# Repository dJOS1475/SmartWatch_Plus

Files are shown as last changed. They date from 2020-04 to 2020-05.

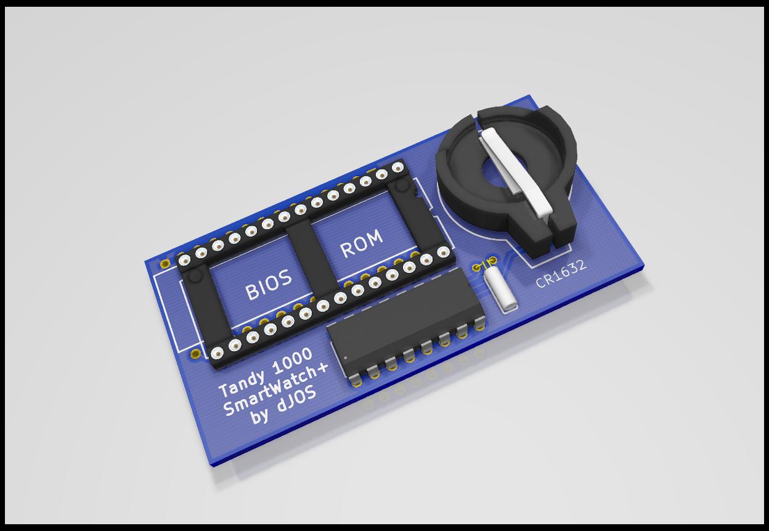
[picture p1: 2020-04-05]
Renders/SmartWatch+.jpg

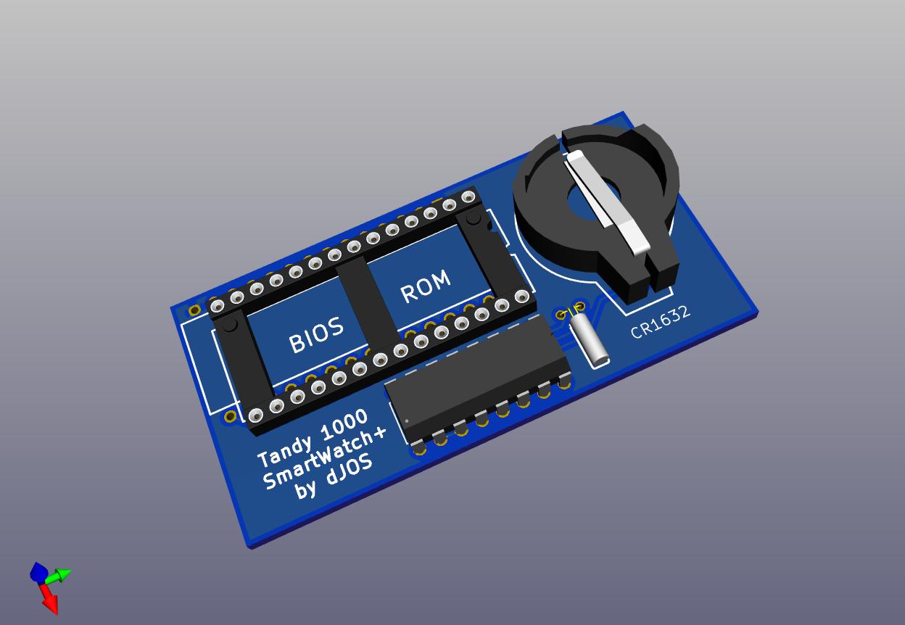
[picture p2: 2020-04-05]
Renders/SmartWatch+_Basic.jpg

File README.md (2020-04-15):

# SmartWatch_Plus
SmartWatch+ Tandy 1000 HX, SX etc Edition

The Tandy 1000 SmartWatch+ module adds a Clock & Calendar to your 1000. All you need to do is install it under the BIOS ROM and then use the Y2K Patched SMWCLOCK.COM utility to set the time automatically via your Autoexec.bat file.

I made this design because the original SmartWatch batteries are now mostly dead and can't be replaced. The 1000 SmartWatch+ uses a standard CR1632 Lithium coin cell for long life and easy replacement.

This HX/SX version should fit most Tandy 1000 machines (except the 1000 EX) but was designed for the HX and SX machines. If it physically fits in your 1000, it will work. it should also work in other PC Clones with a 28 Pin Bios ROM chip.

Y2K SmartWatch Software is here: https://www.dropbox.com/s/kctqpwzjxgymfz9/smwy2k.zip?dl=0

My Store can be found here: https://www.tindie.com/stores/CyberneticSys/

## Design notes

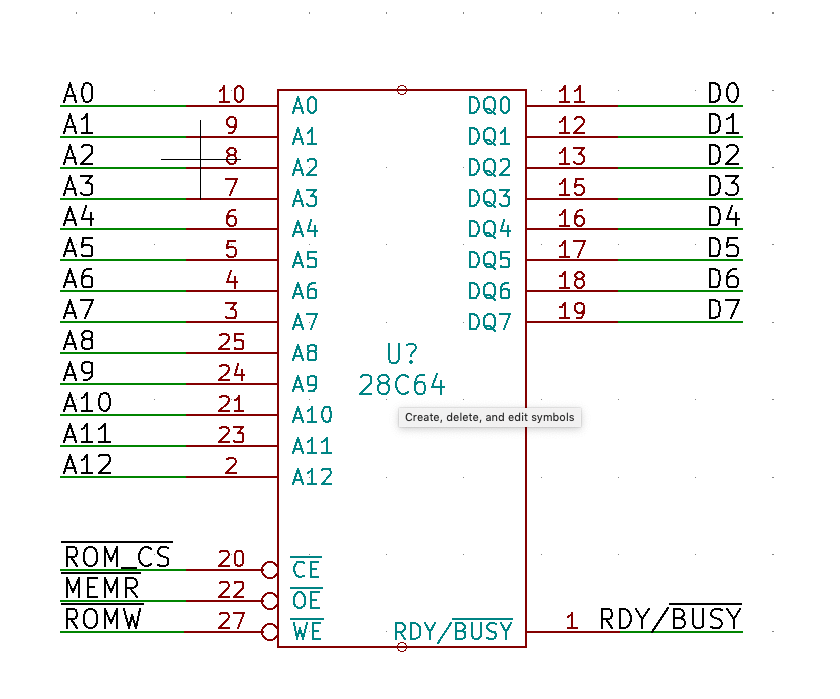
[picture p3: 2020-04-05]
Info/Screenshot 2019-10-07 15.42.38.png

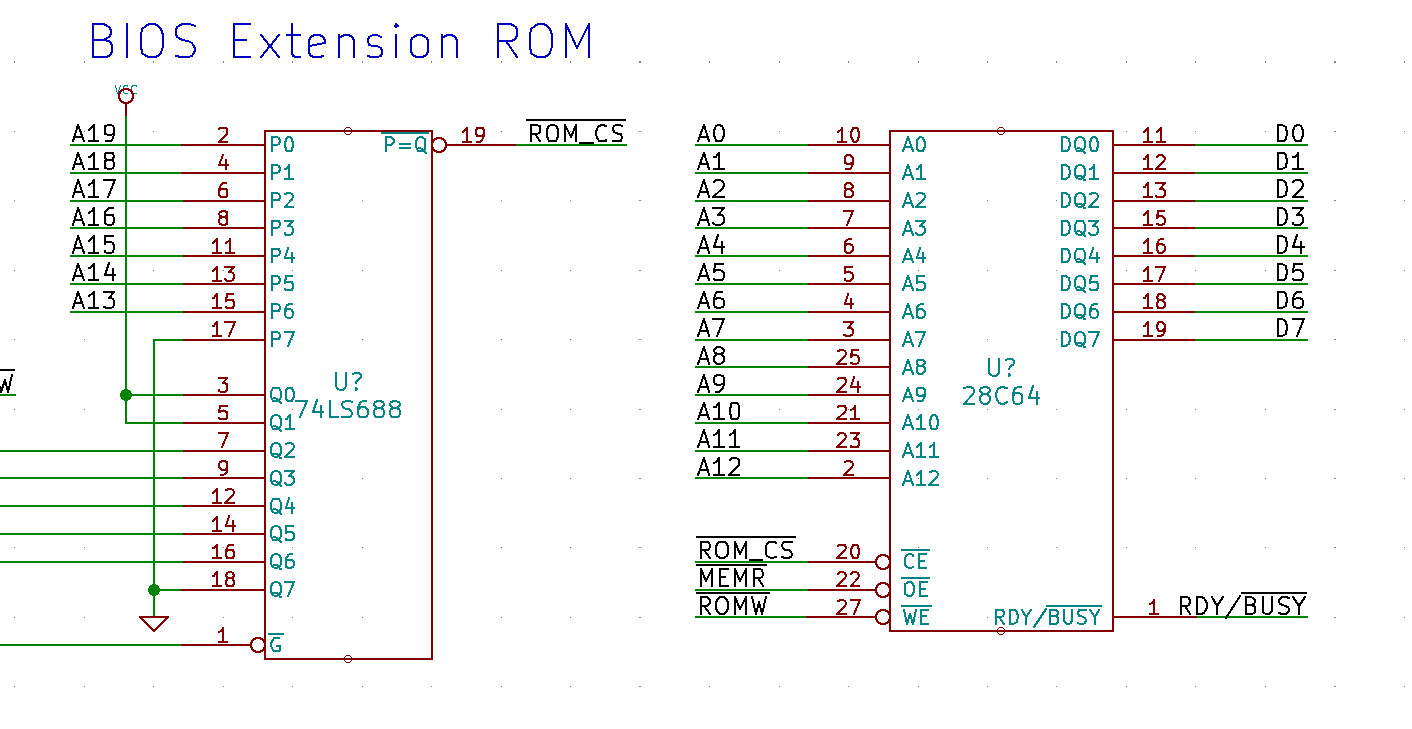
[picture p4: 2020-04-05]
Info/Screenshot 2019-10-07 15.09.33.png

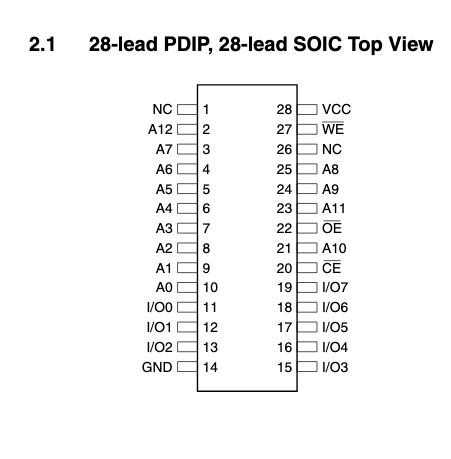
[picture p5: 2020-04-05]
Info/Screenshot 2019-10-07 15.42.36.png

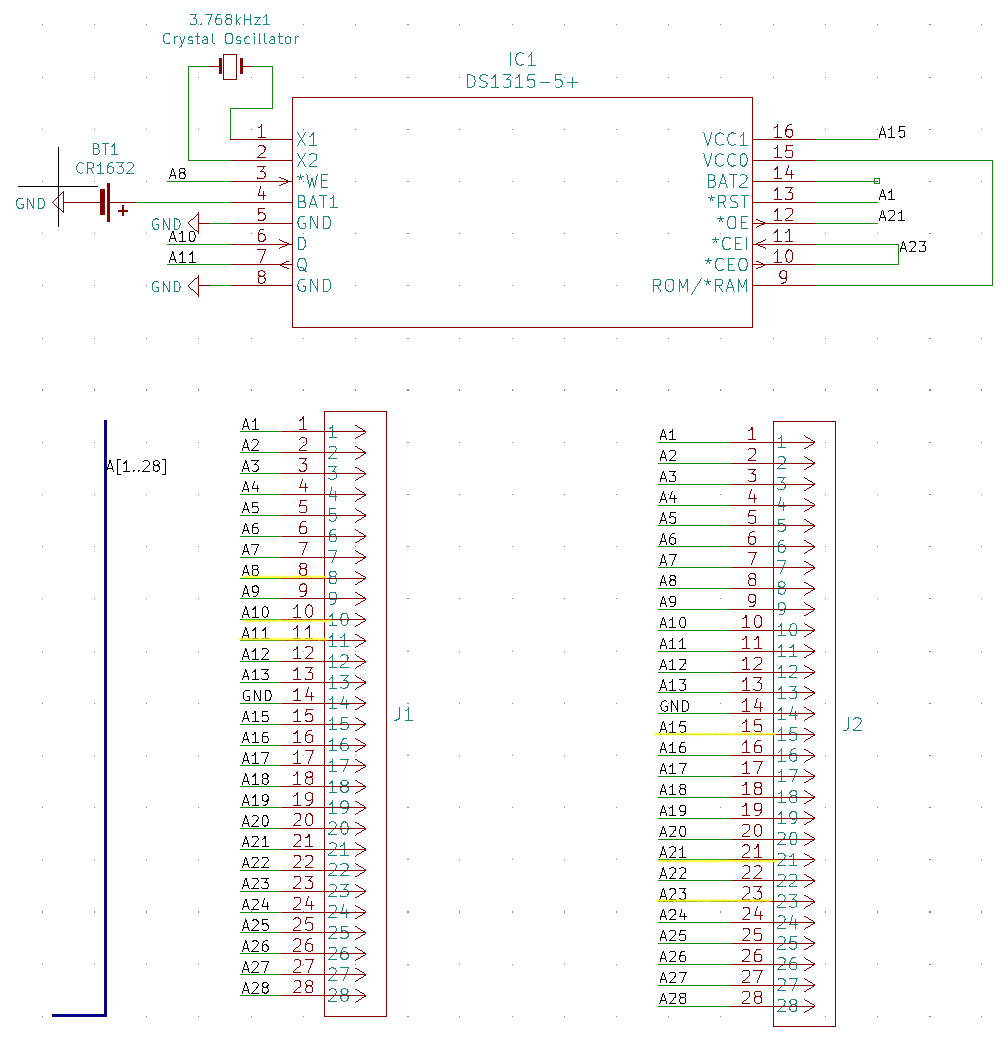
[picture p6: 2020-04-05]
Info/Screenshot 2019-10-07 15.35.17.png

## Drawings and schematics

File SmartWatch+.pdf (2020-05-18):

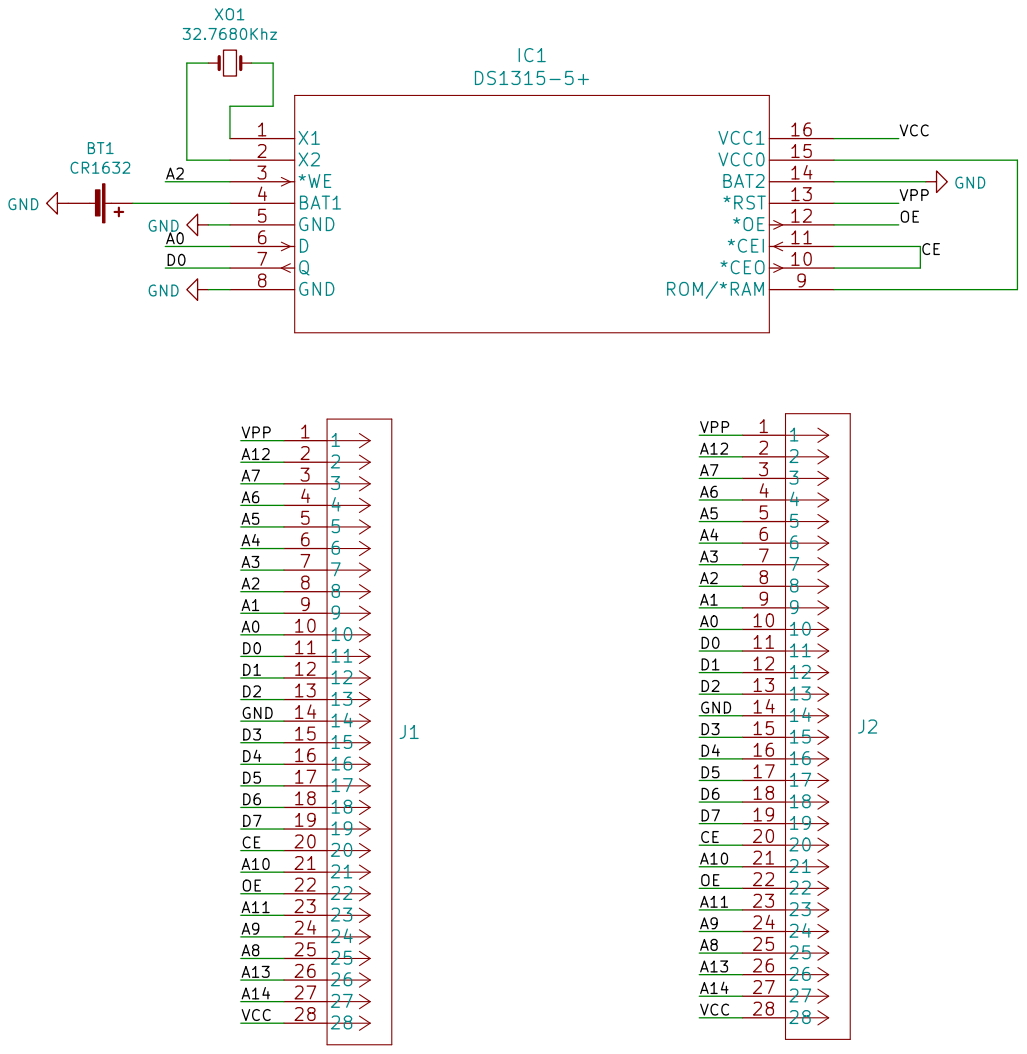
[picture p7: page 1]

Id: 1/1 Title: File: SmartWatch+.sch Sheet: /

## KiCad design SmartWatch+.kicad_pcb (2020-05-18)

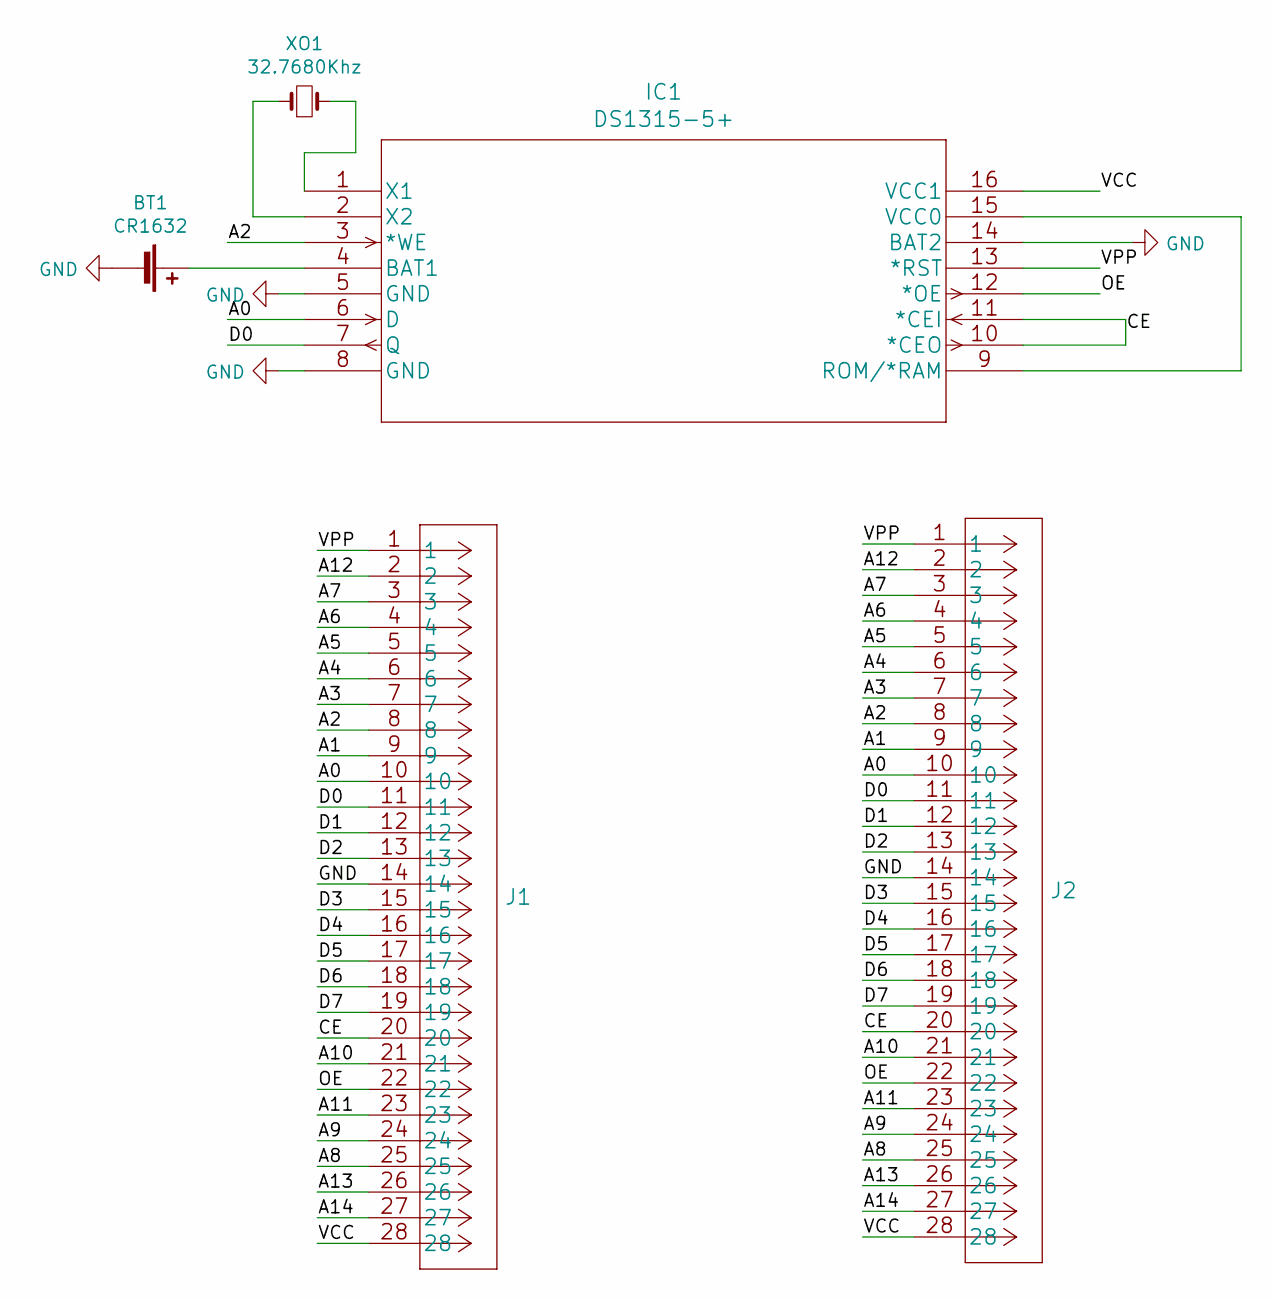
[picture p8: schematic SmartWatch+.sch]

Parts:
BT1: CR1632; BH600
IC1: DS1315-5+; DS1315-5&plus_
J1, J2: 2-1571586-9; DIP-28_600mil_SW
XO1: 32.7680Khz; TC26H

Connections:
/A0: IC1.6 (D), J1.10, J2.10
/A1: J1.9, J2.9
/A2: IC1.3 (*WE), J1.8, J2.8
/A3: J1.7, J2.7
/A4: J1.6, J2.6
/A5: J1.5, J2.5
/A6: J1.4, J2.4
/A7: J1.3, J2.3
/A8: J1.25, J2.25
/A9: J1.24, J2.24
/A10: J1.21, J2.21
/A11: J1.23, J2.23
/A12: J1.2, J2.2
/A13: J1.26, J2.26
/A14: J1.27, J2.27
/CE: IC1.10 (*CEO), IC1.11 (*CEI), J1.20, J2.20
/D0: IC1.7 (Q), J1.11, J2.11
/D1: J1.12, J2.12
/D2: J1.13, J2.13
/D3: J1.15, J2.15
/D4: J1.16, J2.16
/D5: J1.17, J2.17
/D6: J1.18, J2.18
/D7: J1.19, J2.19
/OE: IC1.12 (*OE), J1.22, J2.22
/VCC: IC1.16 (VCC1), J1.28, J2.28
/VPP: IC1.13 (*RST), J1.1, J2.1
GND: BT1.2 (-), IC1.5 (GND), IC1.8 (GND), IC1.14 (BAT2), J1.14, J2.14
unnamed: BT1.1 (+), IC1.4 (BAT1)
unnamed: IC1.1 (X1), XO1.2
unnamed: IC1.2 (X2), XO1.1
unnamed: IC1.9 (ROM/*RAM), IC1.15 (VCC0)

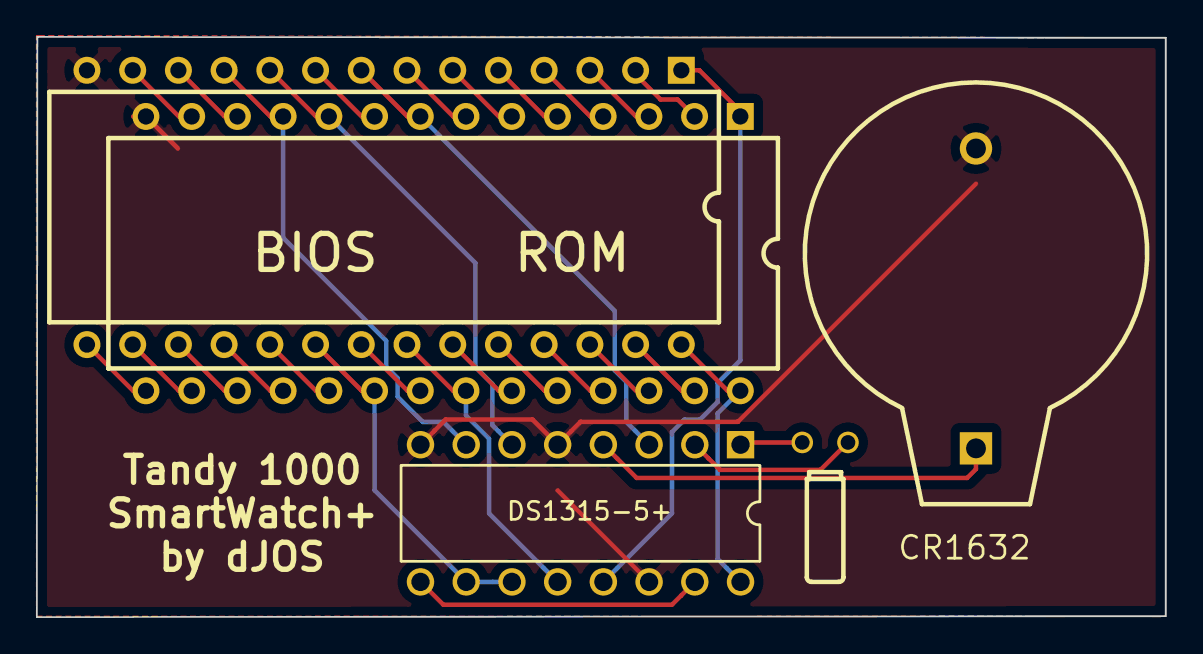
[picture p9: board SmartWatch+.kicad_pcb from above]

Board: 2 copper layers, 62.7 x 32.2 mm, 5 parts (0 on the bottom side), 32 nets.
